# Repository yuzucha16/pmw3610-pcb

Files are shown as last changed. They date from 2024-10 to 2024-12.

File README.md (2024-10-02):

# PMW3610 PCB

[PixArt PMW3610DM-SUDU](https://www.pixart.com/products-detail/21/PMW3610DM-SUDU) low power laser mouse sensor breakout board.

- Base on schematic from [siderakb/pmw3610-pcb](https://github.com/siderakb/pmw3610-pcb).
- Be operated with 3.3V voltage level ONLY.
- Outlined as narrow as possible for side mount horizontally and perpendicular on low profile keyboards.

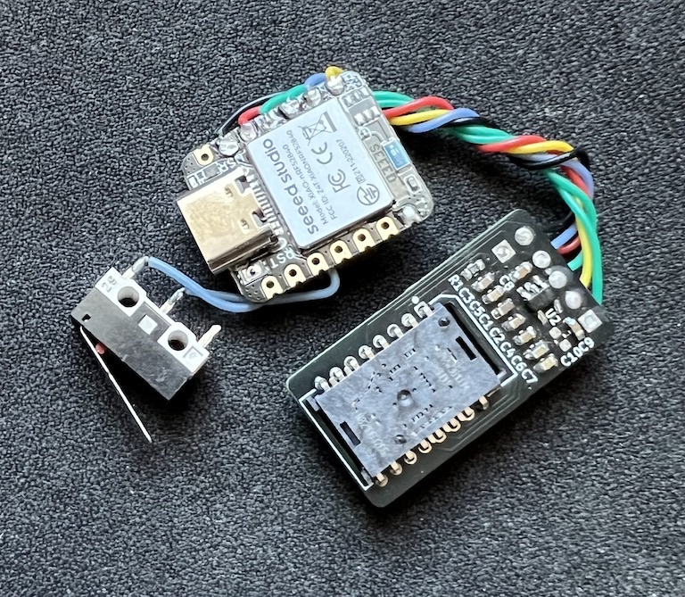
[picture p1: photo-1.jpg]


*Figure 1: Size comparing to Seeed XIAO BLE*

## PCB

Online preview avaliable [here](https://kicanvas.org/?github=https%3A%2F%2Fgithub.com%2Fbadjeff%2Fpmw3610-pcb), powered by [KiCanvas](https://github.com/theacodes/kicanvas).

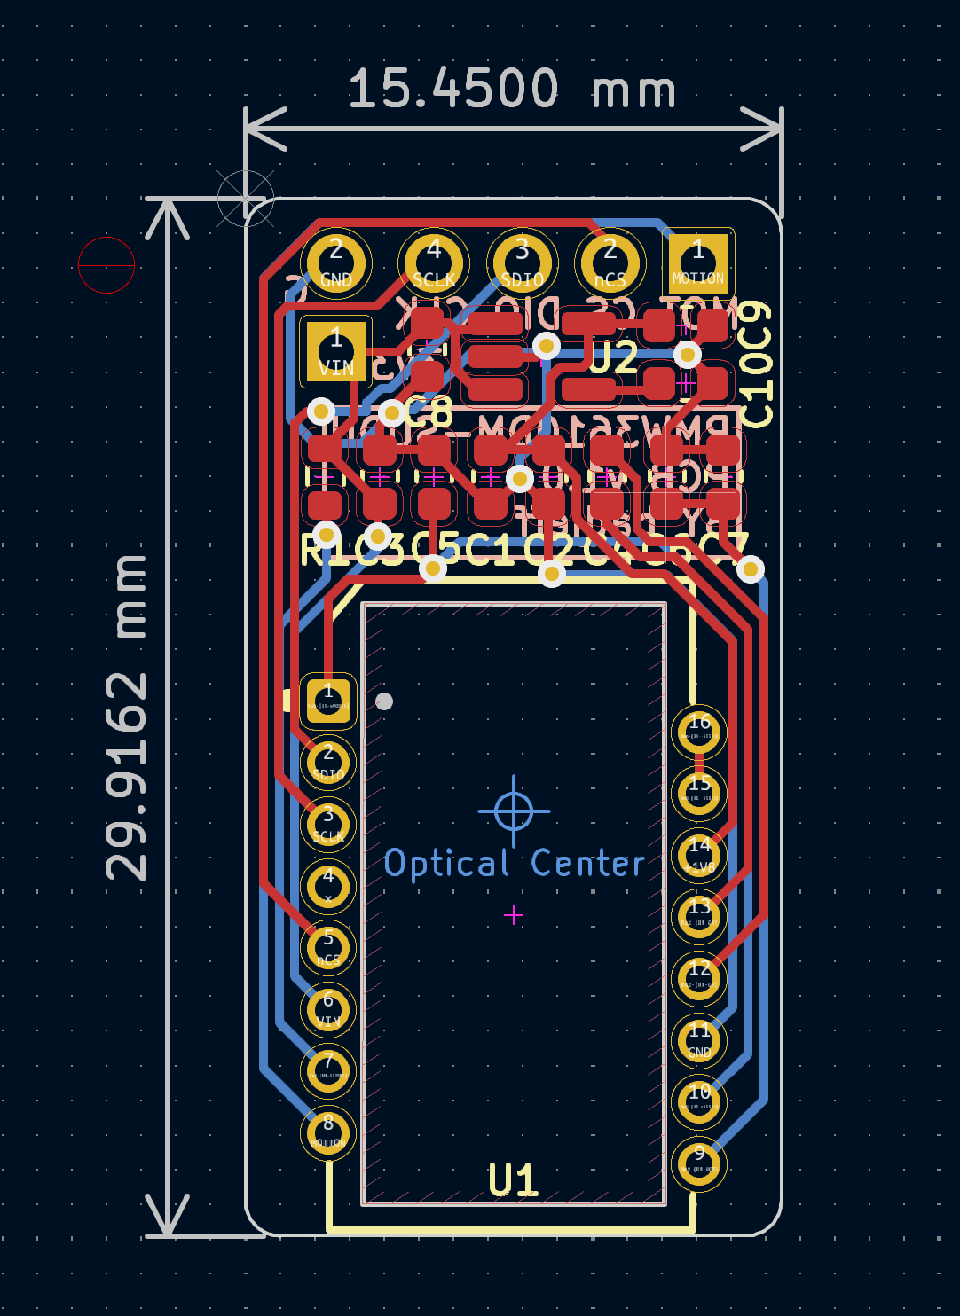
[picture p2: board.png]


*Figure 2: PCB edgecuts dimension*

### BOM

|Ref|Value|Footprint|
|-|-|-|
|C1|3.3uF/16V|SMD 0603|
|C2, C3|100nF|SMD 0603|
|C4|100nF X7R|SMD 0603|
|C5|10nF|SMD 0603|
|C6|10uF X7R|SMD 0603|
|C7|10nF X7R|SMD 0603|
|C8, C9|1uF|SMD 0603|
|C10| DNI |SMD 0603|
|R1|10k|SMD 0603|
|U1|PMW3610|16 Pin|
|U2|TLV74318|SOT-23-5|
|J1, J2|2.54mm Pin header||
- DNI: don't install.
- SMD 0603 (Imperial) aka 1608 Metric.
- PMW3610 needs to be used with LM18-LSI lens.
- `R1` is optional/additional RESET pull up resistor, RESET pin of PMW3610 has a built in weak pull up circuit.
- `U2` LDO can be replace by RT9193-18GB, change `C10` to 22nF.
- Solder extra decoupling capacitors (C4, C6, C7) directly to the pins of the sensor, if needed.

### Board Characteristics

- Copper layer count: 2
- Board thickness: 1.6 mm
- Board overall dimensions: 15.5 x 30 mm

### Voltage level config

- 3.3V logic
- VIN: 3.3V

## License

Available under the [CERN-OHL-P v2](/LICENSE) permissive license.

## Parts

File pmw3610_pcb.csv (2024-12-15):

Designator | Comment | Datasheet | Footprint | Qty | DNP
C1 | 3.3uF/16V | ~ | Capacitor_SMD:C_0603_1608Metric | 1
C2,C3 | 100nF | ~ | Capacitor_SMD:C_0603_1608Metric | 2
C4 | 100nF X7R | ~ | Capacitor_SMD:C_0603_1608Metric | 1
C5 | 10nF | ~ | Capacitor_SMD:C_0603_1608Metric | 1
C6 | 10uF X7R | ~ | Capacitor_SMD:C_0603_1608Metric | 1
C7 | 10nF X7R | ~ | Capacitor_SMD:C_0603_1608Metric | 1
C8,C9 | 1uF | ~ | Capacitor_SMD:C_0603_1608Metric | 2
U2 | TLV74318PDBVR |  | Package_TO_SOT_SMD:SOT-23-5_HandSoldering | 1

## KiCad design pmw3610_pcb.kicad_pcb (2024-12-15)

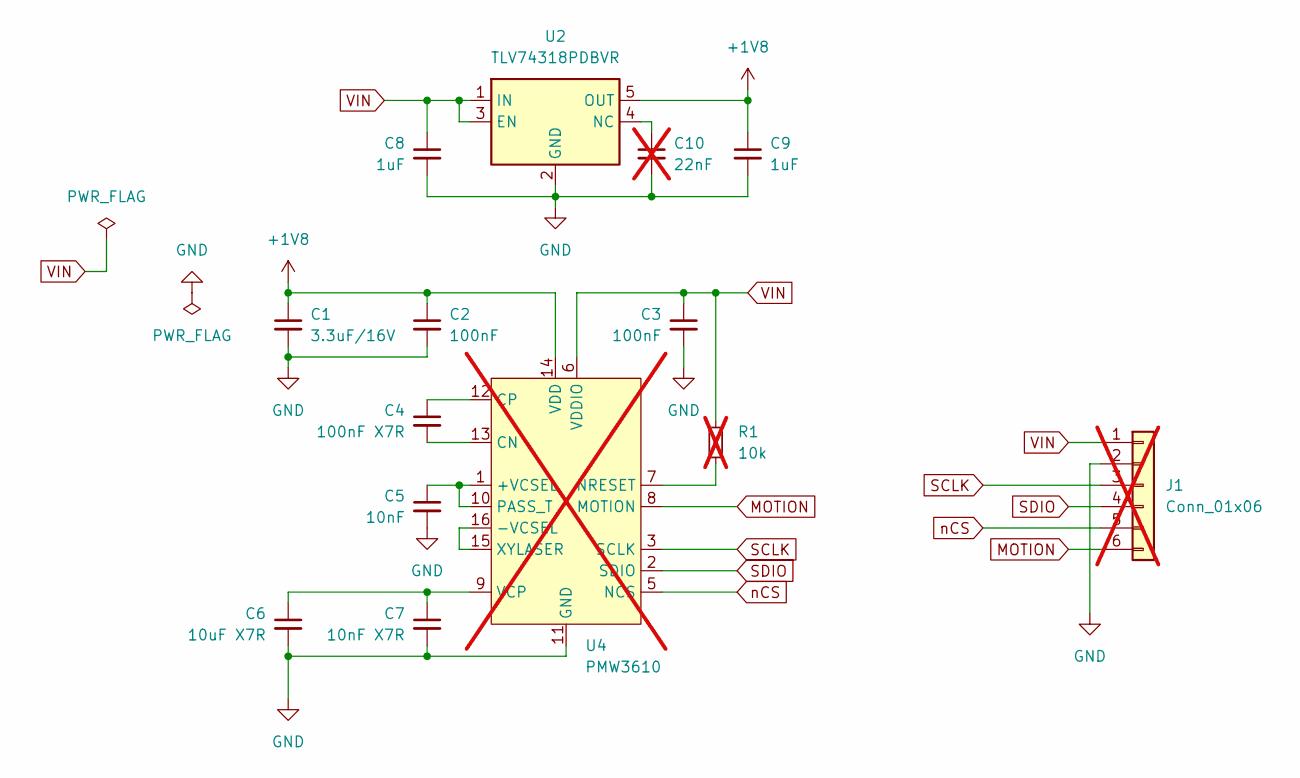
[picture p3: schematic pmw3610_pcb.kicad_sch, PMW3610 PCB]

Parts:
C1: 3.3uF/16V; C_0603_1608Metric
C2, C3: 100nF; C_0603_1608Metric
C4: 100nF X7R; C_0603_1608Metric
C5: 10nF; C_0603_1608Metric
C6: 10uF X7R; C_0603_1608Metric
C7: 10nF X7R; C_0603_1608Metric
C8, C9: 1uF; C_0603_1608Metric
C10: 22nF; C_0603_1608Metric; not fitted
J1: Conn_01x06; PinHeader_1x06_P2.54mm_Vertical; not fitted
R1: 10k; R_0603_1608Metric; not fitted
U2: TLV74318PDBVR; SOT-23-5_HandSoldering
U4: PMW3610; PMW3610DM-SUDU 16Pin; not fitted

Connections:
+1V8: C1.1, C2.1, C9.1, U2.5 (OUT), U4.14 (VDD)
GND: C1.2, C2.2, C3.2, C5.2, C6.2, C7.2, C8.2, C9.2, C10.2, J1.2, U2.2 (GND), U4.11 (GND)
MOTION: J1.6, U4.8 (MOTION)
unnamed: C10.1, U2.4 (NC)
unnamed: C5.1, U4.1 (+VCSEL), U4.10 (PASS_T)
unnamed: U4.15 (XYLASER), U4.16 (-VCSEL)
unnamed: C4.2, U4.13 (CN)
unnamed: C4.1, U4.12 (CP)
unnamed: R1.2, U4.7 (NRESET)
unnamed: C6.1, C7.1, U4.9 (VCP)
SCLK: J1.3, U4.3 (SCLK)
SDIO: J1.4, U4.2 (SDIO)
VIN: C3.1, C8.1, J1.1, R1.1, U2.1 (IN), U2.3 (EN), U4.6 (VDDIO)
nCS: J1.5, U4.5 (NCS)

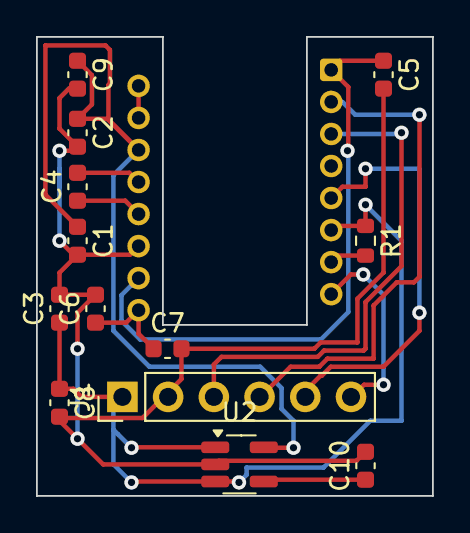
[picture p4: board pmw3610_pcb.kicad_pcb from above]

Board: 2 copper layers, 22.0 x 25.5 mm, 14 parts (1 on the bottom side), 14 nets.

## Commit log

2024-10-01 init commit
    [pmw3610_pcb.kicad_pcb, pmw3610_pcb.kicad_sch]
2024-12-14 modify size (25mm x 22mm)
    [pmw3610_pcb.kicad_pcb, pmw3610_pcb.kicad_sch]
2024-12-14 [jlcpcb] Add order files
    [pmw3610_pcb.csv, pmw3610_pcb.kicad_pcb, pmw3610_pcb.kicad_sch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]
2024-12-15 [V0] for jlcpcb
    [pmw3610_pcb.csv, pmw3610_pcb.kicad_pcb, pmw3610_pcb.kicad_sch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]

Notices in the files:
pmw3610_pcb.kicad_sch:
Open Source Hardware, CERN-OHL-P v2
